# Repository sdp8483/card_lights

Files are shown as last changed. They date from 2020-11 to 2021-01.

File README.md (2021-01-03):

# Greeting Card LEDs

**NOTE** This project is in progress and info may change. More details will be added soon

Add LEDs to your greeting cards. A simple touch of the back side of the device turns on the LEDs. Touch again to turn the LEDs off. A 60 second auto off feature will turn off the LEDs for you when left on to extend battery life.

## Installation

Position the LEDs and PCB on your card in whatever orientation you would like. Avoid bending the LED wires at sharp angles or too many times as the wire will fatigue and break. The back side of the PCB is touch sensitive (the side labeled touch) but may not be the same sensitivity over the entire back. Touch different areas to determine the most sensitive area and position that on your card where you would like the recipient to touch to turn on the LEDs. Attache the PCB using double sided tape or another method of your choosing that will firmly attache it to the greeting card. The LEDs can also be taped down or affixed however you would like.

After installing remove the battery and wait for 30 seconds before reinstalling the battery. Try not to turn on the LEDs while installing the battery. Do not turn on the LEDs for about 60 seconds. During this time the touch controller is calibrating to ensure that it recognizes your finger tip when you touch it.

## Tips and Tricks

### Don't need so many LEDs? 
You can cut them off near the PCB using scissors (probably best to use an pair you don't care about) or wire cutters.

### Increasing Touch Sensitivity
If you find the LEDs do not light up when you touch the back of the PCB you can increase the sensitivity of the touch controller by cutting the jumper JP2. 
TODO: add photos and more

### Adding your own Touch Pad
To add your own touch pad to for example make the whole front of the greeting card touch sensitive cut JP4 and then add solder to bridge JP3. Solder a connection to your new touch pad to the square pad at the bottom of the PCB. You can directly connect the the new touch pad or use wire. Copper tape works great to make a new touch pad. For a lower cost option aluminum foil will also work. Attach it to the greeting card using double sided tape. Tape can be used to attach a wire from the PCB to the aluminum touch pad. TODO: photos

### Ghosts
Does the LEDs appear to turn on without anyone touching them? While we cannot rule out ghosts it is most likely the touch controller being super sensitive. Remove the battery for at least a minute and then reinstall the battery while trying not to trigger the LEDs. Don't touch the PCB for a few  minutes. If that does not solve the problem try changing the battery for a new one. A battery near the end of its light maybe causing the touch controller to act up. If all else fails treat is as a feature and not a bug. The touch controller maybe acting up in your specific situation due to a number of reasons such as the paper material nearby, other items nearby, electrical interference, and more.

## Directory Outline
- [`~/pcb/`](pcb) is for KiCAD design files. Inside is the touch PCB design along with a simple PCB design. The simple PCB design uses a tactile button to turn on the LEDs when held down. It was a prototype and is left in this repository just incase it is needed again. Both designs are single sided (if you don't count the touch pad) and can be easily manufactured at home using a PCB router. The POGO programmer PCB design files are for makeing a POGO board to program the ATTINY10 in circuit. You will need additional devices to program the ATTINY10 in HV mode. Details to be added at a later date.
- [`~/firmware/`](firmware) is for firmware souce code and binaries for the touch PCB. If you want to write you own code start here.
- [`~/enclosure/`](enclosure) is for the POGO programmer and is a holder.

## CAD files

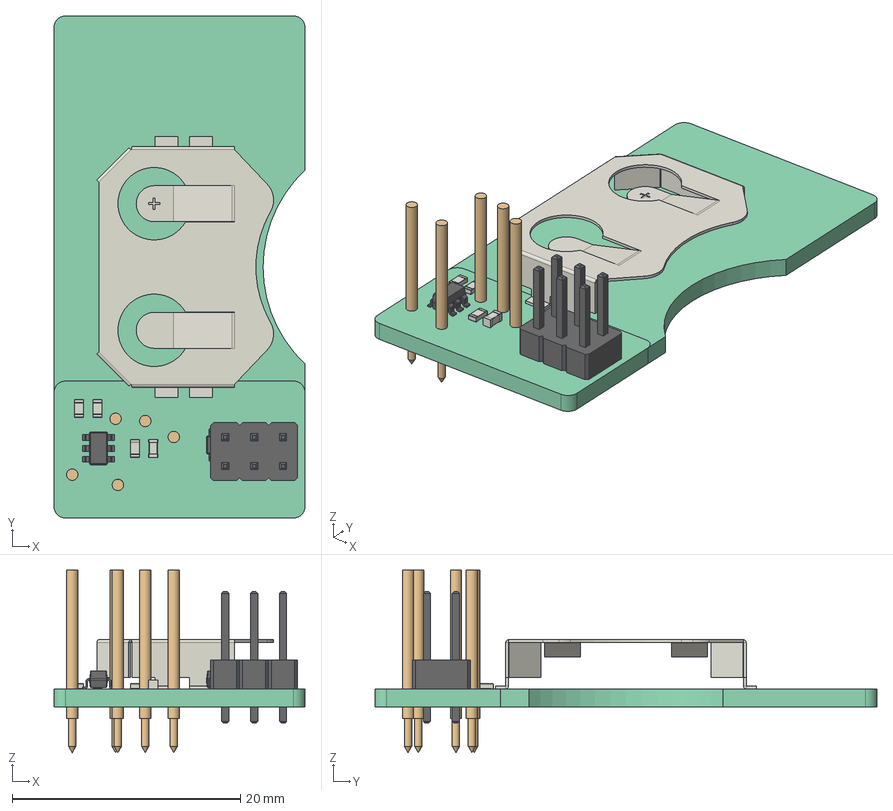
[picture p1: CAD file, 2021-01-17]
enclosure/pogo_programming_fixture.FCStd
22.0 x 44.0 x 16.0 mm
Pcb_6817
BT1_BAT-HLD-001_5FEFA458
U2_SOT_23_6_5FDEA3F8
U1_SOT_23_6_5FEFA628
R1_R_0603_1608Metric_5FDE9693
R2_R_0603_1608Metric_5FDE96F9
C1_C_0603_1608Metric_5FDE23A3
C2_C_0603_1608Metric_5FDEA3C3
R3_R_0603_1608Metric_5FDE958B
C3_C_0603_1608Metric_5FEE1F42
Pcb_71ce
J6_pl_pogo_1mmDia_16mmL_5FEFBDE3
J5_pl_pogo_1mmDia_16mmL_5FEFBDDE
J4_pl_pogo_1mmDia_16mmL_5FEFBDD9
J3_pl_pogo_1mmDia_16mmL_5FEFBDD4
J2_pl_pogo_1mmDia_16mmL_5FEFBDCF
J1_PinHeader_2x03_P254mm_Vertical_5FEFC2E1

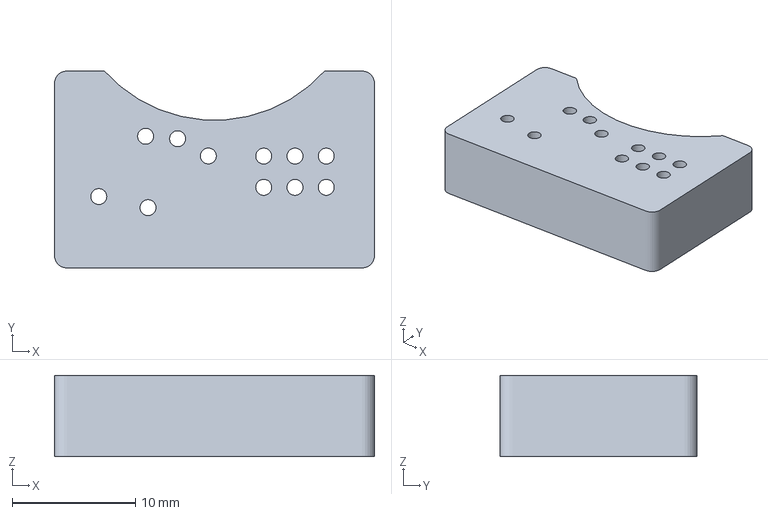
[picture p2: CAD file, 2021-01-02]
enclosure/pogo_holder.amf
26.0 x 16.0 x 6.60 mm

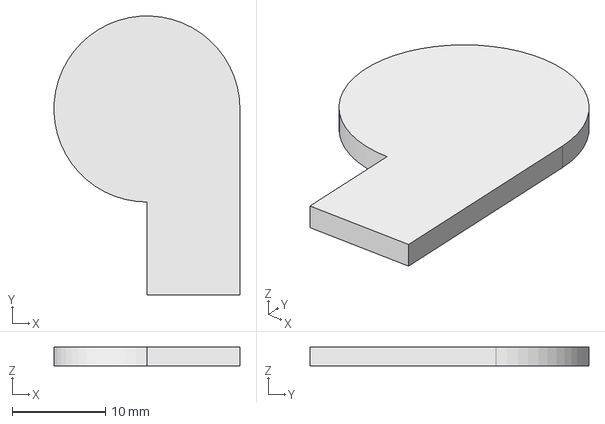
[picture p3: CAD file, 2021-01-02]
enclosure/CR2032_simulator.FCStd
20.0 x 30.0 x 2.00 mm

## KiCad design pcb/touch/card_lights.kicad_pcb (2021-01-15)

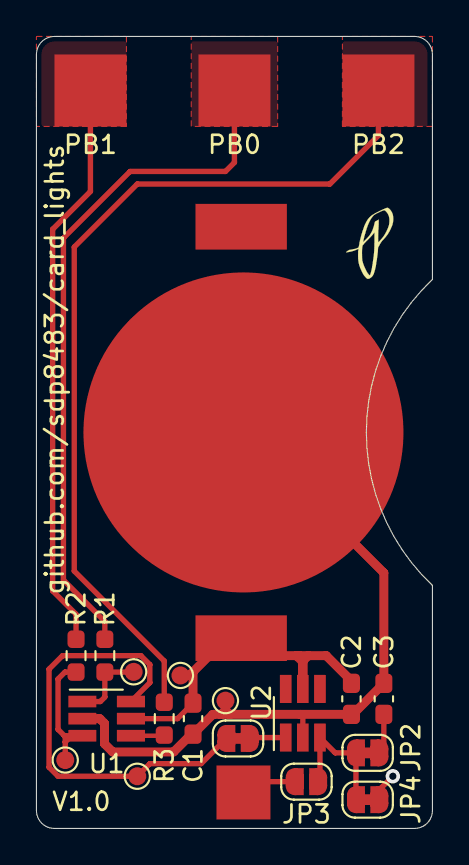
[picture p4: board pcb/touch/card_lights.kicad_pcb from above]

Board: 2 copper layers, 22.0 x 44.0 mm, 22 parts (0 on the bottom side), 13 nets.

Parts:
BT1: Battery_Cell; BAT-HLD-001
C1, C2: 100n; C_0603_1608Metric_Pad1.08x0.95mm_HandSolder
C3: 10p; C_0603_1608Metric_Pad1.08x0.95mm_HandSolder
J2, J3, J4: LED_PAD; TestPoint_Pad_4.0x4.0mm
JP1, JP2, JP4: Jumper_NC_Small; SolderJumper-2_P1.3mm_Bridged_RoundedPad1.0x1.5mm
JP3: Jumper_NC_Small; SolderJumper-2_P1.3mm_Open_RoundedPad1.0x1.5mm
R1, R2, R3: 91; R_0603_1608Metric_Pad0.98x0.95mm_HandSolder
TP1, TP2, TP3, TP4, TP5: TestPoint; TestPoint_Pad_D1.0mm
TP6: TestPoint; TestPoint_Pad_3.0x3.0mm
U1: ATtiny10-TS; SOT-23-6_Handsoldering
U2: TTP223E-HA6; SOT-23-6_Handsoldering

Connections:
+3V0: BT1.1, C1.2, C2.2, TP1.1, U1.5, U2.5
/PB0: R1.2, TP2.1, U1.1
/PB1: R2.2, TP3.1, U1.3
/PB2: R3.2, U1.4
/PB3: JP1.1, TP4.1, U1.6
/TOUCH: JP2.1, JP3.1, JP4.1, U2.3
GND: BT1.2, C1.1, C2.1, C3.2, TP5.1, U1.2, U2.2
unnamed: C3.1, JP2.2
unnamed: J2.1, R1.1
unnamed: J3.1, R2.1
unnamed: J4.1, R3.1
unnamed: JP1.2, U2.1
unnamed: JP3.2, TP6.1

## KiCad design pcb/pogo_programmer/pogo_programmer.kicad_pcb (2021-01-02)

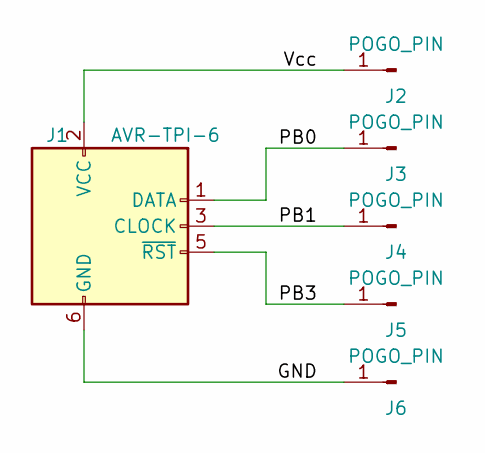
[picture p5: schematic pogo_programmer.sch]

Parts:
J1: AVR-TPI-6; PinHeader_2x03_P2.54mm_Vertical
J2, J3, J4, J5, J6: POGO_PIN; pl_pogo_D1mm

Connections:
/GND: J1.6 (GND), J6.1
/PB0: J1.1 (DATA), J3.1
/PB1: J1.3 (CLOCK), J4.1
/PB3: J1.5 (~RST), J5.1
/Vcc: J1.2 (VCC), J2.1

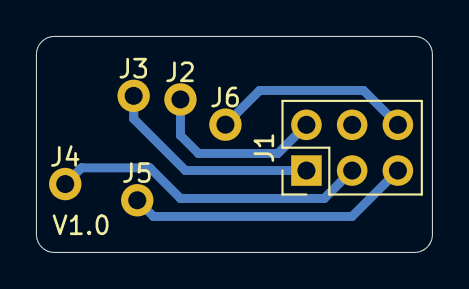
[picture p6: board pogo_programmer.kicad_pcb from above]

Board: 2 copper layers, 22.0 x 12.0 mm, 6 parts (0 on the bottom side), 5 nets.

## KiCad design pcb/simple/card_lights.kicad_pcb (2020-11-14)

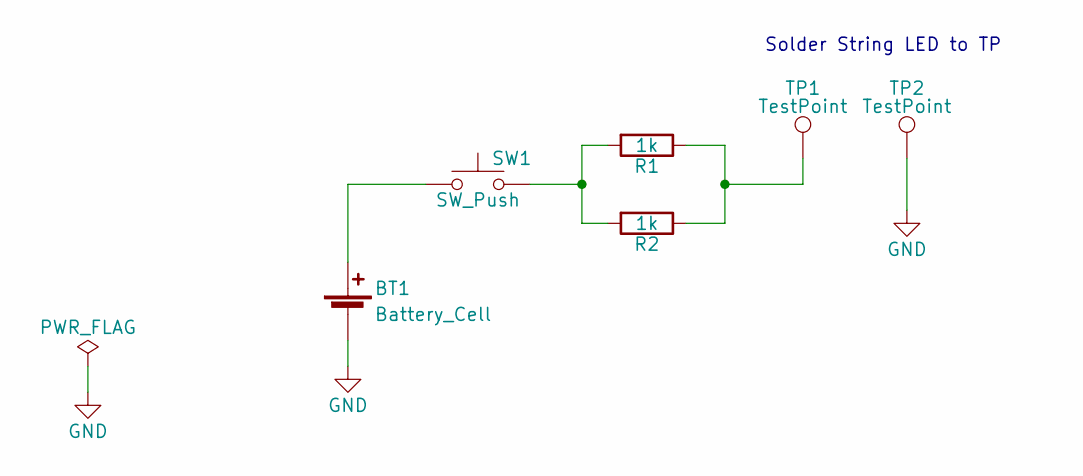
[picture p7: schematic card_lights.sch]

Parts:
BT1: Battery_Cell; BAT-HLD-001
R1, R2: 1k; R_0603_1608Metric_Pad0.98x0.95mm_HandSolder
SW1: SW_Push; Bright_TSA123G60-250
TP1, TP2: TestPoint; TestPoint_Pad_4.0x4.0mm

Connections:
GND: BT1.2 (-), TP2.1
unnamed: BT1.1 (+), SW1.1
unnamed: R1.1, R2.1, TP1.1
unnamed: R1.2, R2.2, SW1.2

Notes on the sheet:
Solder String LED to TP

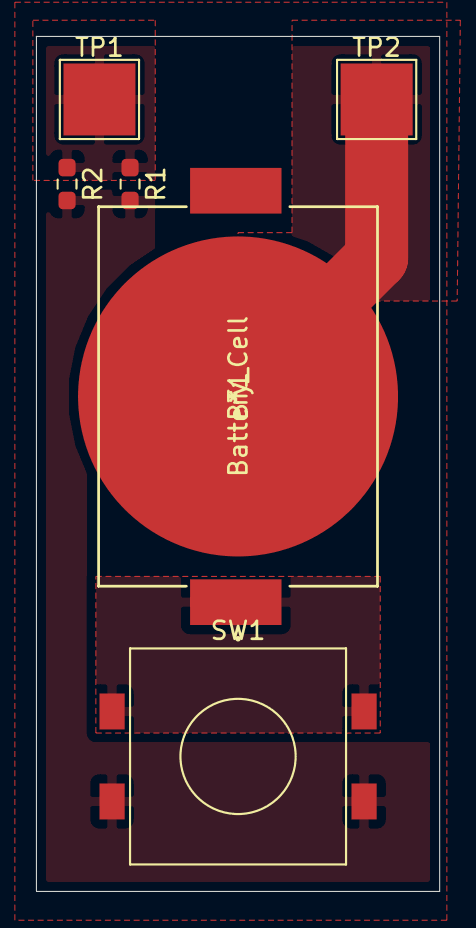
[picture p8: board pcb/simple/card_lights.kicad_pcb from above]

Board: 2 copper layers, 22.4 x 47.5 mm, 6 parts (0 on the bottom side), 4 nets.

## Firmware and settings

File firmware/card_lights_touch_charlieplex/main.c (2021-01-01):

/* Card Lights Touch Edition
 *  using external capacitive touch controller to trigger LEDs
 * 
 * Clk: 1MHz
 * Simple Conneciton Diagram
 *       ATTINY10
 *       ---------
 *   3v | 5  1 PB0| -> LED1
 *   GND| 2  3 PB1| -> LED2
 *      |    4 PB2| -> LED3
 *      |    6 PB3| -> TOUCH_INPUT
 *       ---------
 *        SOT23-6
 * write fuse:
 *      avrdude -c usbasp -p t10 -U fuse:w:0xFE:m
 * 
 * verify fuse:
 *      avrdude -c usbasp -p t10 -t
 *      read fuse
 *      q
 * 
 */

#define F_CPU 1000000UL     /* for delay funcitons */

#include <stdint.h>
#include <avr/io.h>
#include <avr/interrupt.h>
#include <avr/sleep.h>

#include "main.h"
#include "charlieplex.h"
#include "state_machine.h"

/* LED Patterns - choose one to uncomment */
//#define SIMPLE      /* No pattern, constant on */
#define TWINKLE     /* LEDs randomly twinkle */

#if defined(SIMPLE)
#elif defined(TWINKLE)
#include "twinkle.h"
#endif

/* set to achive desired auto off delay */
#define TIMER_PRELOAD   (58594) /* with precaler of 1024 on Timer0, 58,594 is ~60s when sys clock is 1MHz */
//#define TIMER_PRELOAD   (7500) /* with a prescaler of 1024 on Timer0, 7,500 is ~60s when sys clock is 128kHz */

/* state machine state, volatile since ISR can change it */
volatile States_t state = SLEEP;

/* Funciton Prototypes */
void initPCINT0(void);
void enableTimer0(void);
void disableTimer0(void);

int main (void) {
    /* Change Clk Frequency */
    //CCP = 0xD8;         /* write to config control protecitn reg to change CLK registers */
    //CLKMSR = 0b01;      /* use internal 128kHz */
    //CLKPSR = 0b0000;    /* set div by 1 */

    /* make sure LEDs are off */
    charliePlex(0);

    /* setup PB3 as input */
    DDRB &= ~BIT3;
    //PUEB |= BIT3; /* enable internal pullup */

    /* initialize interrupt on PB3 */
    initPCINT0();

    /* set sleep mode */
    set_sleep_mode(SLEEP_MODE_PWR_DOWN);

    /* enable global interrupts */
    sei();          

    while (1) {   
        switch (state) {
            case SLEEP:
                charliePlex(0);     /* turn off LEDs */
                disableTimer0();    /* turn off timer0 to save power */
                sleep_enable();     /* enable sleep */
                sleep_cpu();        /* go to sleep */
                sleep_disable();    /* wake from sleep here on PB3 pin change interrupt */
                break;
            case RUN:
                #if defined(SIMPLE)
                for (uint8_t j=0; j<6; j++) {
                    charliePlex(j+1);
                }
                #elif defined(TWINKLE)
                twinkleLED();
                #endif

                break;
            default:            /* something is wrong, just sleep */
                state = SLEEP;
                break;
        } /* switch(state) */
    } /* while(1) */
} /* main(void) */

/* ==== Funcitons ==== */
/* initialize pin change interrupt service routine */
void initPCINT0(void) {
    PCICR |= BIT0;  /* pin change interrupt enable */
    PCMSK |= BIT3;  /* pin change interrupt on PB3/PCINT3 */
}

/* pin change interrupt service routine */
ISR(PCINT0_vect){
    /* only trigger on low to high  */
    if ((PINB & BIT3)) {
        if (state == SLEEP) {
            state = RUN;    /* wake up and run */
            enableTimer0(); /* enable timer0 to set auto power off */
        } else {
            state = SLEEP;
        }
    }
}

/* eanble timer0 to trigger ISR for auto power off */
void enableTimer0(void) {
    TCCR0A = 0;                         /* OC0A/OC0B disconnected ie no output on pins*/
    TCCR0B = (BIT3 + BIT2 + BIT0);      /* clear timer on compare,  timer prescaler is 1024*/

    OCR0AH = (TIMER_PRELOAD >> 8);      /* set output compare register high byte */
    OCR0AL = (TIMER_PRELOAD & 0xFF);    /* set output compare register low byte */

    TCNT0H = 0;                         /* set timer count to zero */
    TCNT0L = 0;

    TIMSK0 |= (1 << OCIE0A);            /* enable ISR on Output compare A match */
}

/* disable timer0 when sleeping to save power */
void disableTimer0(void) {
    TCCR0A = 0;
    TCCR0B &= ~(BIT2 + BIT1 + BIT0);    /* set timer prescaler to 0 to disable */

    TIMSK0 &= ~(1 << OCIE0A);           /* disable ISR */
}

ISR(TIM0_COMPA_vect) {
    state = SLEEP;  /* auto power off */
}

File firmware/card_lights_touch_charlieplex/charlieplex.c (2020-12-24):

#include "charlieplex.h"

/* charlieplex, turn on LED number */
void charliePlex(int8_t led) {
    /* set all as input to tristate before setting up pin modes below */
    charliePlexTristateAll();

    switch (led) {
        case 0:
            /* do nothing since outputs are already tristated */
            break;
        case 1:
            DDRB |= (BIT0 + BIT1);  /* set PB0 and PB1 as outputs */
            PORTB |= BIT0;          /* set PB0 high */
            PORTB &= ~BIT1;         /* set PB1 low */
            break;
        case 2:
            DDRB |= (BIT0 + BIT1);  /* set PB0 and PB1 as outputs */
            PORTB |= BIT1;          /* set PB1 high */
            PORTB &= ~BIT0;         /* set PB0 low */
            break;
        case 3:
            DDRB |= (BIT1 + BIT2);  /* set PB1 and PB2 as outputs */
            PORTB |= BIT1;          /* set PB1 high */
            PORTB &= ~BIT2;         /* set PB2 low */
            break;
        case 4:
            DDRB |= (BIT1 + BIT2);  /* set PB1 and PB2 as outputs */
            PORTB |= BIT2;          /* set PB2 high */
            PORTB &= ~BIT1;         /* set PB1 low */
            break;
        case 5:
            DDRB |= (BIT0 + BIT2);  /* set PB0 and PB2 as outputs */
            PORTB |= BIT0;          /* set PB0 high */
            PORTB &= ~BIT2;         /* set PB2 low */
            break;
        case 6:
            DDRB |= (BIT0 + BIT2);  /* set PB0 and PB2 as outputs */
            PORTB |= BIT2;          /* set PB2 high */
            PORTB &= ~BIT0;         /* set PB0 low */
            break;    
        default:
            /* something is wrong */
            break;
    }

    _delay_us(ON_DELAY_US);

}

void charliePlexTristateAll(void) {
    /* set all as input to tristate */
    DDRB &= ~(BIT0 + BIT1 + BIT2);
    PORTB &= ~(BIT0 + BIT1 + BIT2);
}

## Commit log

2020-11-14 init commit
    [card_lights.kicad_pcb, card_lights.sch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]
2020-12-19 move previous simple button pcb to seperate dir
    [card_lights.kicad_pcb, card_lights.sch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]
2020-12-19 create touch PCB
    [card_lights.kicad_pcb, card_lights.sch]
2020-12-19 round corners, cutout to grab coin cell
    [card_lights.kicad_pcb]
2020-12-20 output gerbers
    [card_lights.kicad_pcb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]
2020-12-20 create ibom
    [card_lights.kicad_pcb]
2020-12-21 diable timer during sleep, no pullup
2020-12-31 add touch sensitivity adjustment capacitor
    [card_lights.sch]
2020-12-31 add diode to RESET for insystem HV programming that does not damage TTP223E
    [card_lights.sch]
2020-12-31 add test points for in system programming
    [card_lights.sch]
2020-12-31 annotate and add footprints
    [card_lights.sch]
2021-01-01 add new components, start making pretty for PCB manufacture
    [card_lights.kicad_pcb, card_lights.sch]
2021-01-01 update touch controller to not use output toggle
    [card_lights.kicad_pcb, card_lights.sch]
2021-01-01 pcb layout changes
    [card_lights-B_Cu.gbr, card_lights-B_Mask.gbr, card_lights-B_SilkS.gbr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]
2021-01-02 create pogo pin board
    [pogo_programmer.kicad_pcb, pogo_programmer.sch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]
2021-01-02 create cr2032_simulator
    [CR2032_simulator.FCStd]
2021-01-15 generate ibom
    [card_lights.kicad_pcb]

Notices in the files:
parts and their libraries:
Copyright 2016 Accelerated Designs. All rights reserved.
